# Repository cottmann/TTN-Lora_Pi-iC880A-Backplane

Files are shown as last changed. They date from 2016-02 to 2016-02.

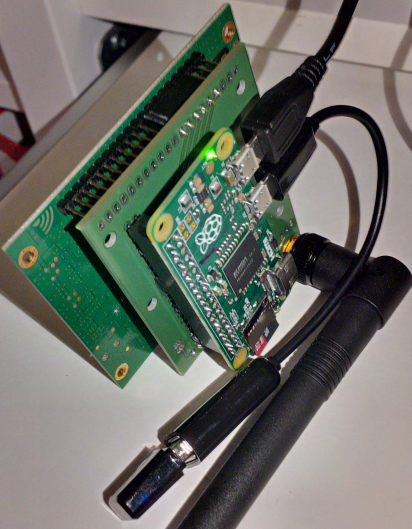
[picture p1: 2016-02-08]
doc/Board_v2_mounted_160208-small.png

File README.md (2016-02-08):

Lora TTN Backplane for iC880A and Raspberry Pi Zero
=================================================

Eagle PCB files for a [Things Network](http://thethingsnetwork.org/) Lora Gateway.

Provides a backplane to mount
* IMST iC880A LoRaWAN Concentrator 868MHz (http://www.wireless-solutions.de/products/long-range-radio/ic880a)
* Raspberry Pi Zero. 

Notes
-----------

1 The Pi Zero does not have a fuse, so the iC880A is powered through the Pi. 
You can also power *the whole unit* through two pads provided on the board (but then don't also power the Pi). 

2 For setup see https://github.com/ttn-zh/ic880a-gateway -- but you need to set the gateway_ID in local_conf.json manually, because the script looks for the MAC address of the ethernet port, but you need the MAC of the WLAN dongle. 

License Information
-------------------
Created by Tobias Cottmann, 2016

This library is released under the [Creative Commons ShareAlike 4.0 International](https://creativecommons.org/licenses/by-sa/4.0/) license. 
You are welcome to use this library for commercial purposes.

If you use this for your project and find it useful, please send me an email with the link.

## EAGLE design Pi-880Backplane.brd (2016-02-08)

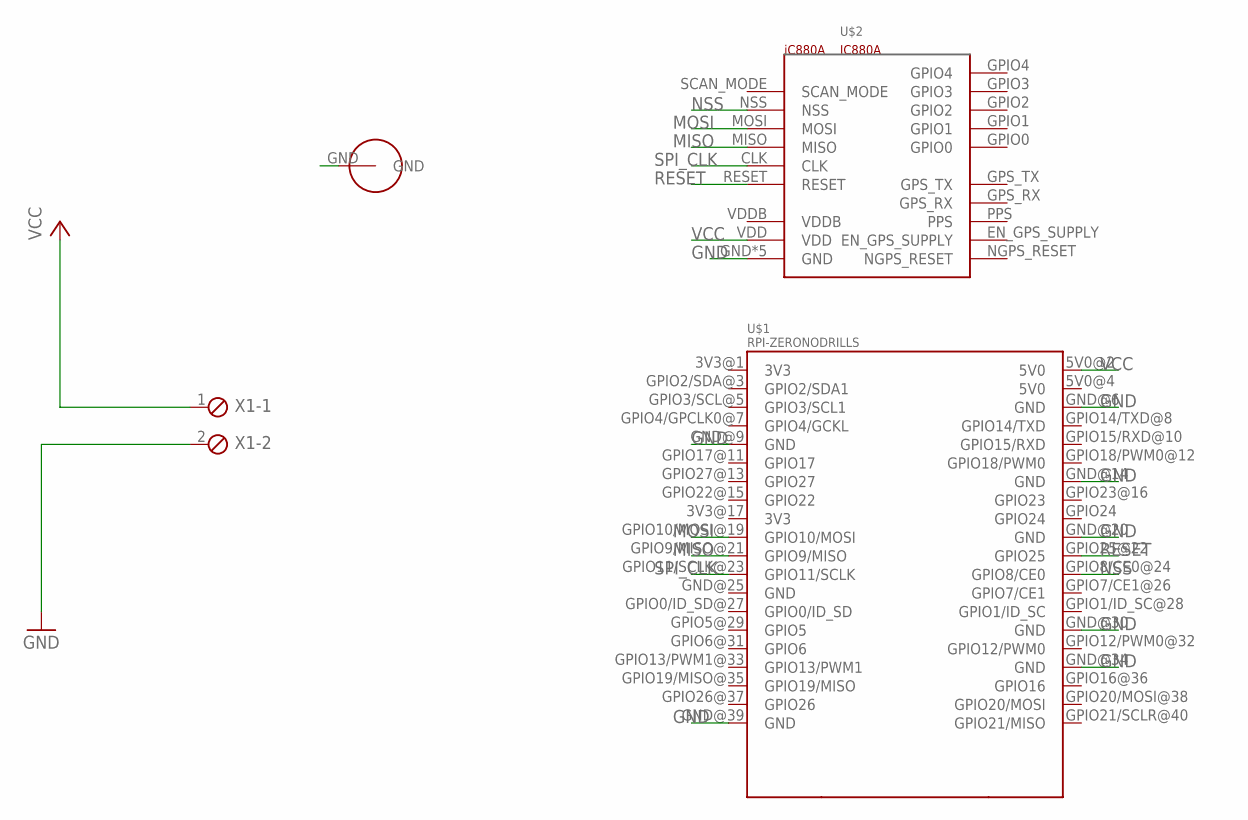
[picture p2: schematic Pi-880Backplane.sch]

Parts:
U$1: RPI-ZERONODRILLS; RPI-ZERO-NODRILLS
U$2: IC880A
U$3: SMA-PIGTAIL-MOUNT
X1: MPT2; 2POL254

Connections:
GND: U$1.GND@6 (GND), U$1.GND@9 (GND), U$1.GND@14 (GND), U$1.GND@20 (GND), U$1.GND@30 (GND), U$1.GND@34 (GND), U$1.GND@39 (GND), U$2.GND, U$2.GND2 (GND), U$2.GND3 (GND), U$2.GND4 (GND), U$2.GND5 (GND), U$3.GND, X1.2
MISO: U$1.GPIO9/MISO@21 (GPIO9/MISO), U$2.MISO
MOSI: U$1.GPIO10/MOSI@19 (GPIO10/MOSI), U$2.MOSI
NSS: U$1.GPIO8/CE0@24 (GPIO8/CE0), U$2.NSS
RESET: U$1.GPIO25@22 (GPIO25), U$2.RESET
SPI_CLK: U$1.GPIO11/SCLK@23 (GPIO11/SCLK), U$2.CLK
VCC: U$1.5V0@2 (5V0), U$2.VDD, X1.1

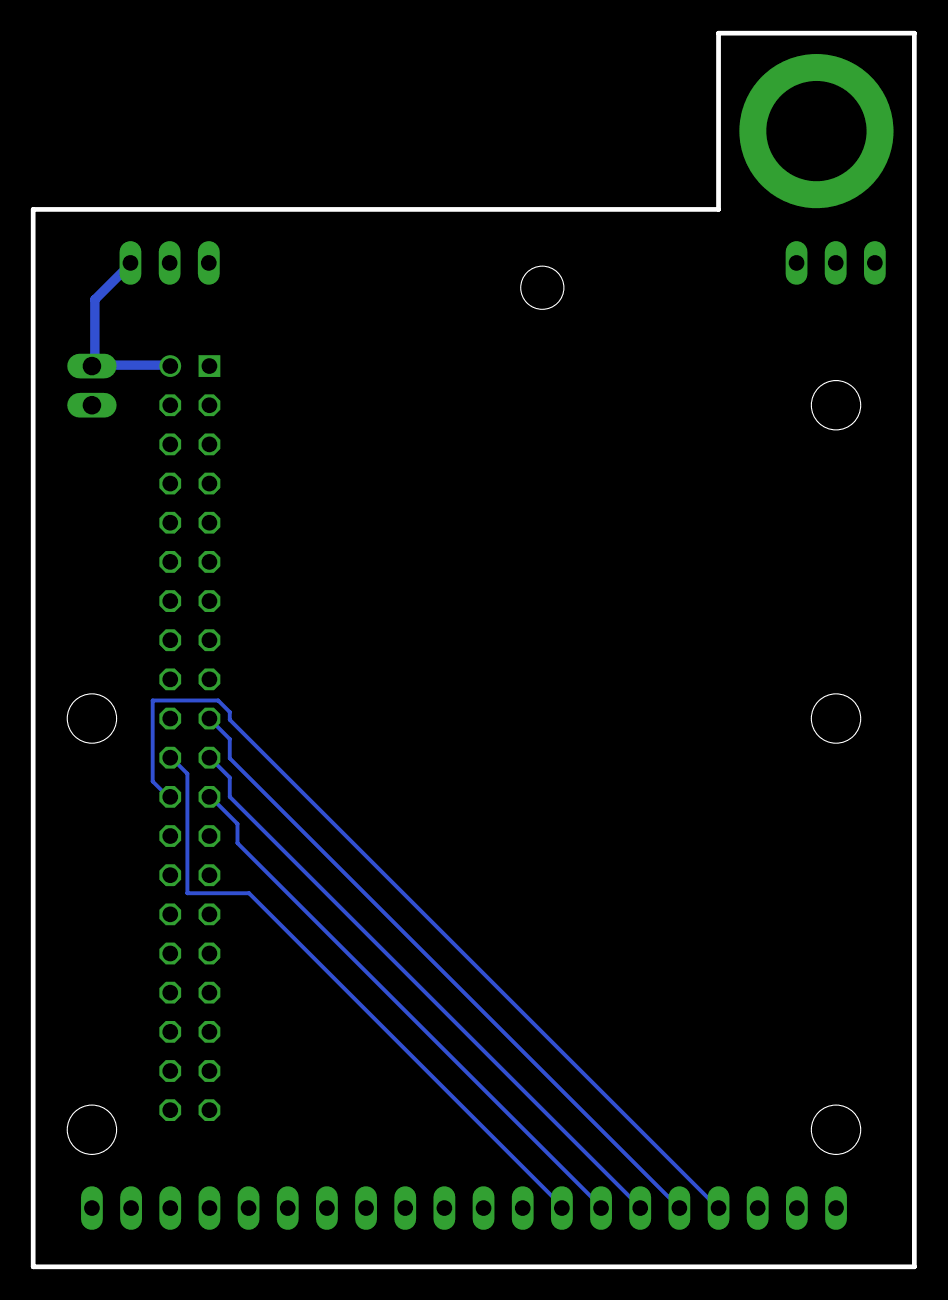
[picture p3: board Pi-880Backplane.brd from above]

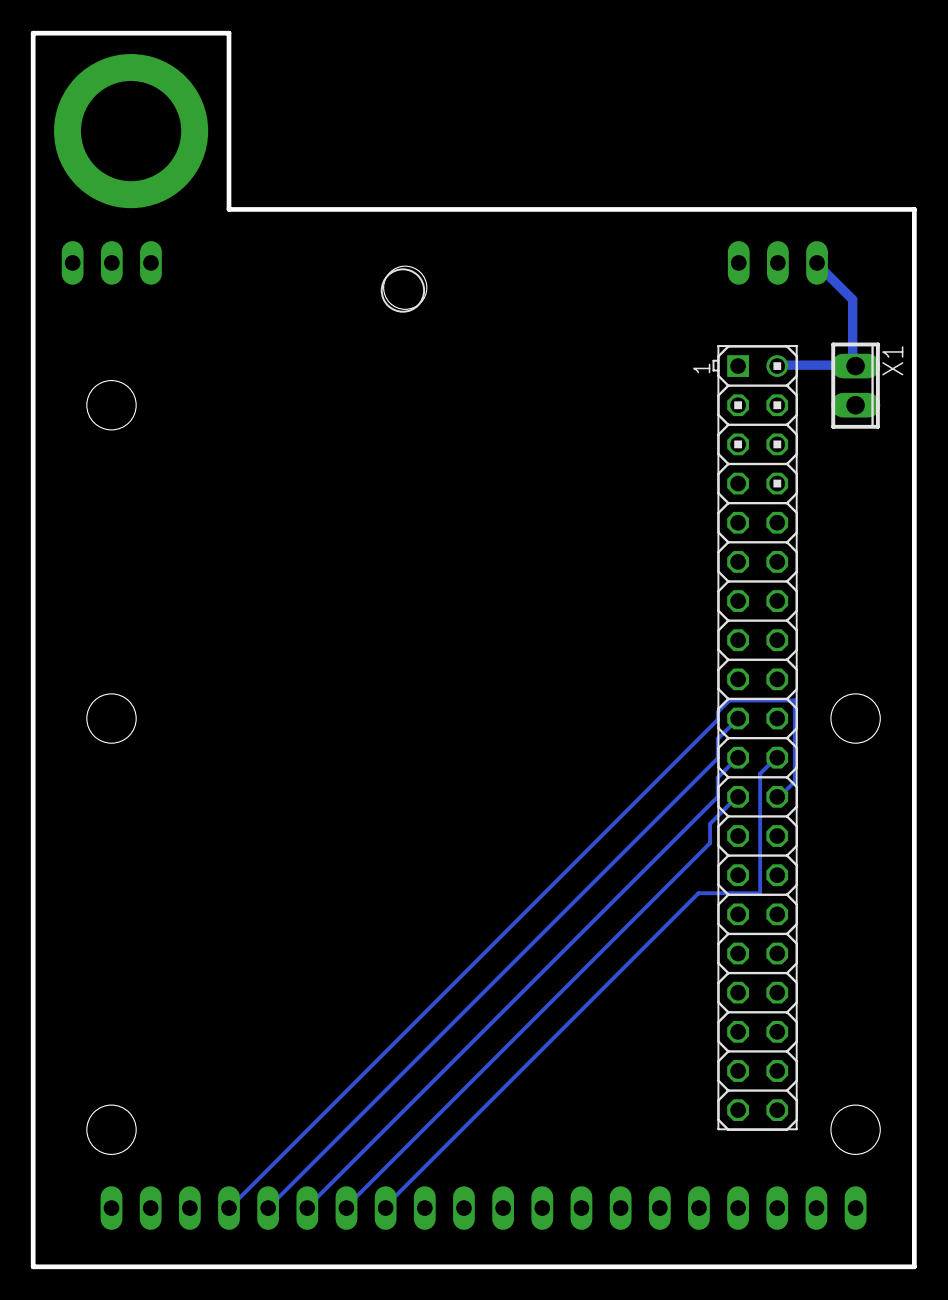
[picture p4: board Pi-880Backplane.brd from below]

Board: 2 copper layers, 57.1 x 80.0 mm, 4 parts (2 on the bottom side), 7 nets.

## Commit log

2016-01-10 version 1
    one-sided. relatively large board.
    [Pi-880Backplane.brd, Pi-880Backplane.sch]
2016-01-16 First board
    [Pi-880Backplane.brd]
2016-02-06 Drill holes bigger
    [Pi-880Backplane.brd, Pi-880Backplane.sch]
2016-02-07 Better SMA mount
    [Pi-880Backplane.brd, Pi-880Backplane.sch]
2016-02-08 Merged v2
    [Pi-880Backplane.brd, Pi-880Backplane.sch]
2016-02-08 Add mounting hole for the Pi
    But board is too small to also have mounting holes for the iC880A.
    [Pi-880Backplane.brd, Pi-880Backplane.sch]
